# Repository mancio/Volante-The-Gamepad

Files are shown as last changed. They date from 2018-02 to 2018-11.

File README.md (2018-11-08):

# Volante-The-Gamepad
The new revolutionary joystick for car and flight simulation games.

*(Design still in progress 😆)*

&nbsp;

<p align="center">

</p>

*carbon 3d preview*

&nbsp;

<p align="center">

</p>

*3d preview with classic ABS box*

&nbsp;

<p align="center">
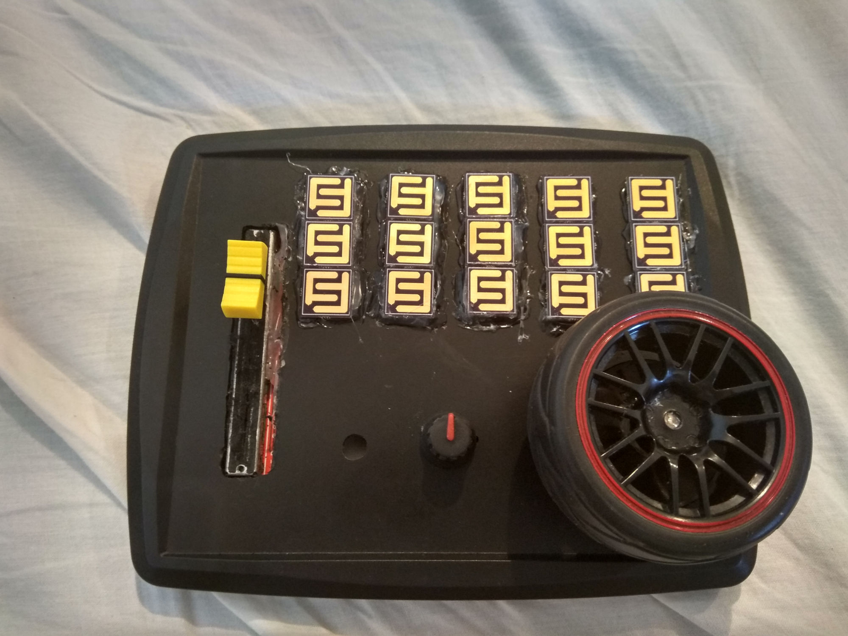
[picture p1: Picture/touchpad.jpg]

</p>   

*prototype with home-made touch buttons*

&nbsp;

<p align="center">
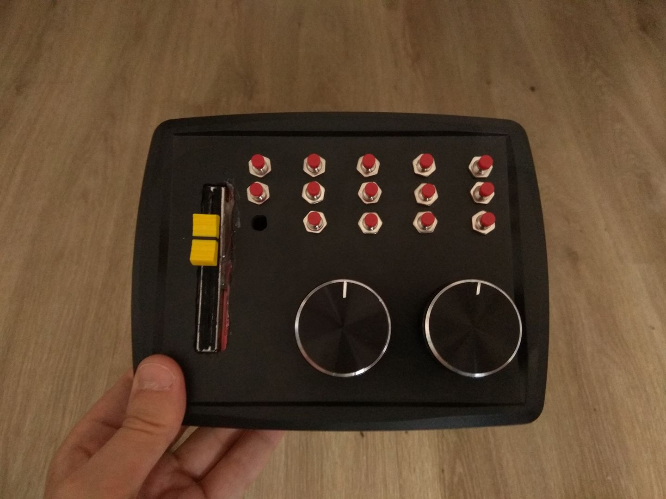
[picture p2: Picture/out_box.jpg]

</p>   

&nbsp;

*prototype with classic RC remote buttons*

### Software 
The code is written by using the famous libray ```Joystick.h```. You can find some sketches still in testing [here](https://github.com/mancio/Volante-The-Gamepad/tree/master/Volante%20sketch).
After some tests seem that only the ```JOYSTICK_TYPE_JOYSTICK``` configuration works. Unfortunately Microsoft stop to support the HID human interface and only the basic function works. Still no solution for force feedback and particular multiaxis joystick.... now the more complex gaming simulation devices have their own drivers. You don't need the basic plug and play driver. Please have a look for the [HID architecture](https://docs.microsoft.com/en-us/windows-hardware/drivers/hid/) to understand and maybe help 😵

### Hardware
The hardware include a joystick case, buttons, knobs, the [Arduino Pro Micro](https://www.sparkfun.com/products/12640) and the the shield to interface the Arduino with the gamepad hw. The button pad modules and the shield boards are designed with [KiCad](http://kicad-pcb.org/). You can find on [OSH Park](https://oshpark.com) the PCBs ready to print.
1. [First design - only push buttons](https://oshpark.com/shared_projects/Fl5pqxbd)
2. [Second design - esternal pull-up resistors](https://oshpark.com/shared_projects/2LW72doK)

### Directory structure
1. [ArduinoJoystickLibrary-master](https://github.com/mancio/Volante-The-Gamepad/tree/master/ArduinoJoystickLibrary-master) - the Joystick library written by [Matthew Heironimus](https://github.com/MHeironimus)

2. [Fritzing](https://github.com/mancio/Volante-The-Gamepad/tree/master/Fritzing) - The Fritzing project with a prototype on breadbord. A small sketch to give a basic idea.

3. [Picture](https://github.com/mancio/Volante-The-Gamepad/tree/master/Picture) - some pictures for the Fritzing design project and the building process

4. [Volante sketch](https://github.com/mancio/Volante-The-Gamepad/tree/master/Volante%20sketch) - the code
   
   - [Volante](https://github.com/mancio/Volante-The-Gamepad/blob/master/Volante%20sketch/Volante/Volante.ino) - the main Arduino sketch. The sketch is design to be used with touch, capacitive and push buttons. The I/O pin can be in PULL-UP, PULL-DOWN or FLOAT configuration. 
      - touch button design: The PINs change to LOW when the finger or any not-hi-resistance organic object connect both the pad tracks. The finger and each resistor on the shield should be considered part of a voltage devider. Your dry skin should have an internal resistance of 2 MOhm so the resistors on the shield should be >= 10 MOhm. You can use [this](http://www.ohmslawcalculator.com/voltage-divider-calculator) voltage devider calculator to calculate the resistor value. The Arduino pin mosfets are LOW state when the input is about <= 2.5V. If you use a less conductive material to close the contacts of the pad maybe you will have to raise the resistance up to 20MOhm. Remeber that an high resistance voltage devider make the input *(dancing* 🎶 *)*. You could see the button blipping when you touch the button pad (only one contact or both). This effect is usualy caused by the power supply cord (I'm testing on a laptop). To reduce this effect you should a cercamic capacitor between the input and the ground. The capacitor store a small charge when you press the button and release it very slowly due to the very high value resistors. This stop the flipping but introduce a small delay. You should try some caps between 100pF (101 value) - 100nF (104 value) until your find the best compromise for your application. I suggest 10nF (103 value) capacitor.
      
      [Here](https://www.tinkercad.com/things/0KRsWQPfhxv) Some experiments on ThinkerCad.
      
      &nbsp;
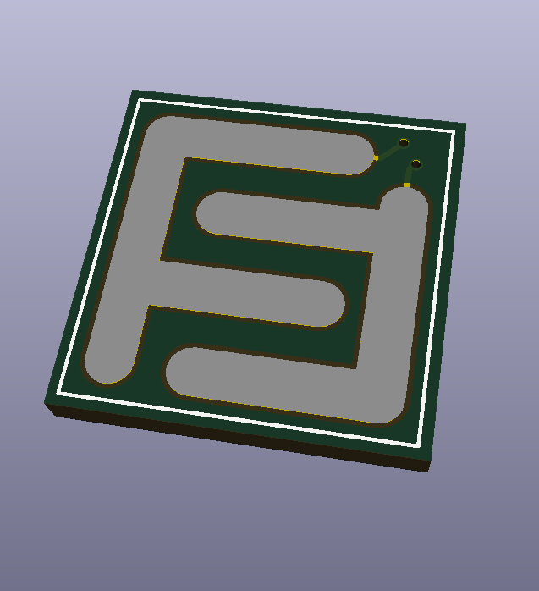
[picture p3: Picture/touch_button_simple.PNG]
      
      *touch button pad (the resistors are on the shield)* 
      &nbsp;
      
      - capacitive design: you can use the [TTP223](https://infusionsystems.com/support/TTP223.pdf) touch module as push button Normally LOW. The button switch on/off by using an internal timer that estimate the change of the capacitive charge during a fixed time slice. I suggest this configuration only for fast operation where is not required precision. The buttons are fast to trigger but sensible to external environment (high probability of fake positive) and the chip autoreset after few seconds (do not use as acceleretor button in a game)  
      
      &nbsp;
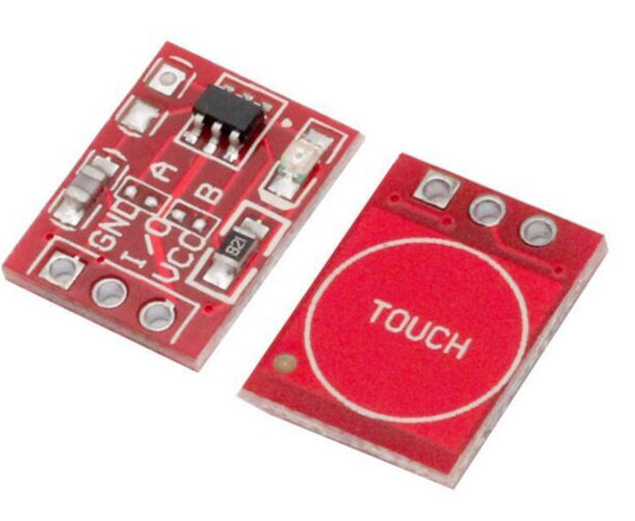
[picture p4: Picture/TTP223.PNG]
      
      *capacitive module* 
      &nbsp;
      
      - classic push button design: you can set up NO (normally open push button) using a pull-up configuration to reduce bouncing effects. When you push the button the pin will be GND. This is the most simple configuration, the button will be very reactive but harder to trigger (the most of NO push buttons are hard to click)
      
      &nbsp;
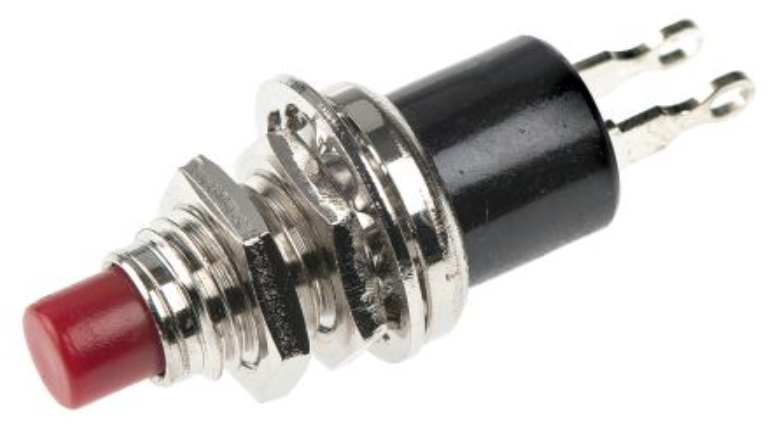
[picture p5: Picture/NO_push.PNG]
      
      *NO Momentary push button for RC* 
      &nbsp;

   - [test](https://github.com/mancio/Volante-The-Gamepad/blob/master/Volante%20sketch/test/test.ino) - Used to check the buttons assignment. 
   
      - int wiring[18] = Arduino pin in the IDE
      - int binding[18] = Buttons of joystick lib
      - String pull_mask[18] = pin state? High Low float (depending by the button type used)
      - analog_mask[18] = is analog? (for example pot is analog and push button is digital)
      
      Write the button structure with arrays here, execute the code and check in the table if the button binding is correct. If the binding satisfy your magic fingers copy this configuration to the main code ``Volante.ino``

5. [kicad](https://github.com/mancio/Volante-The-Gamepad/tree/master/kicad) - the Kicad scheme and PCB project.

   - [buttons_layout](https://github.com/mancio/Volante-The-Gamepad/tree/master/kicad/buttons_layout) - the blueprint of the gamepad case with RC push buttons
   
   - [buttons_layout_touch](https://github.com/mancio/Volante-The-Gamepad/tree/master/kicad/buttons_layout_touch) - the blueprint of the gamepad case with touch buttons
   
   - [lib](https://github.com/mancio/Volante-The-Gamepad/tree/master/kicad/lib) - kicad libraries of this project (include in kicad before open the project)
   
   - [shield](https://github.com/mancio/Volante-The-Gamepad/tree/master/kicad/shield) - firrst shield design only for capacitive and push buttons
   
      &nbsp;
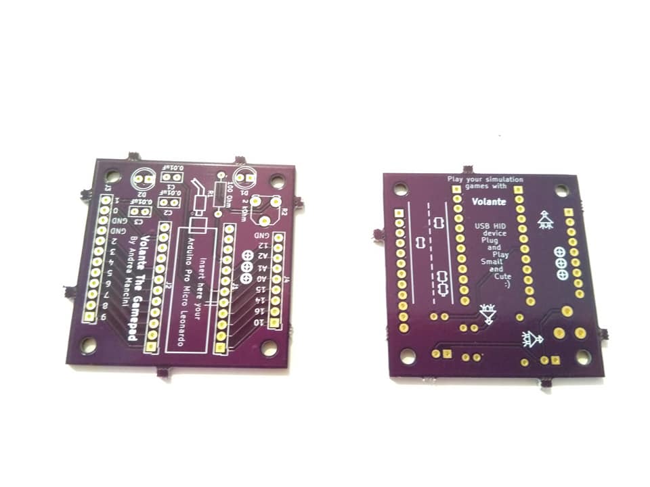
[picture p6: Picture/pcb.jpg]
      
      *First PCB printed by OSH Park* 
      &nbsp;
      
      &nbsp;
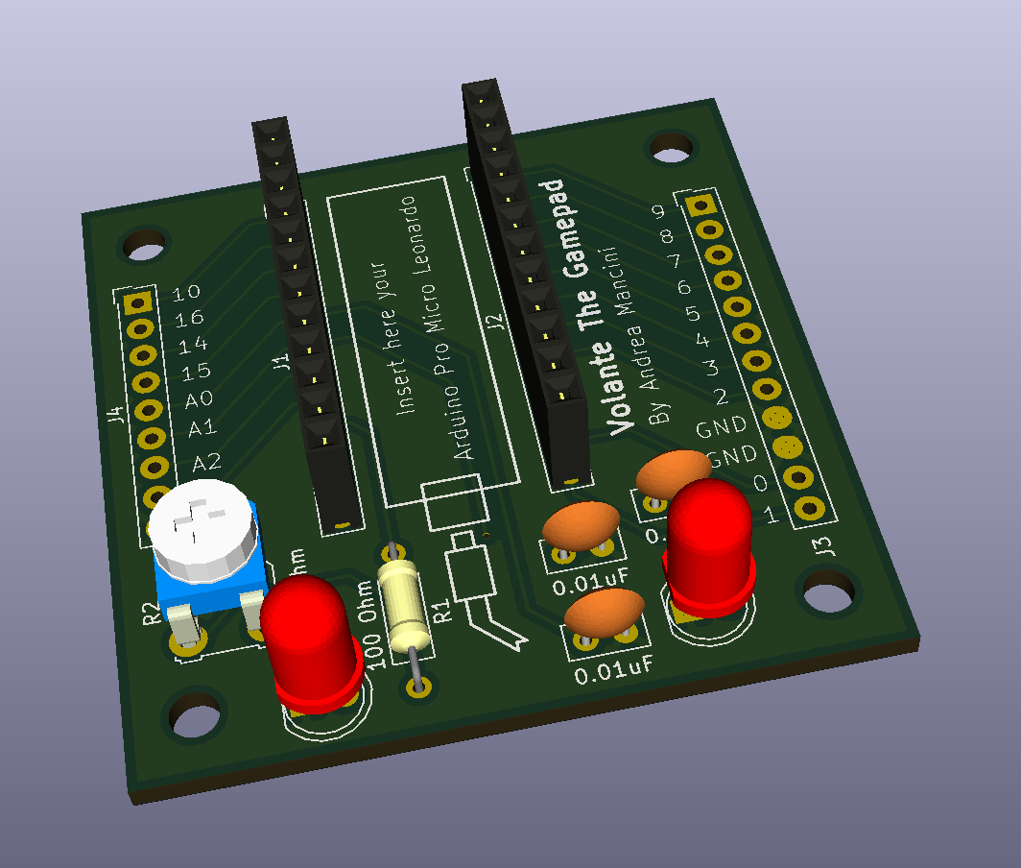
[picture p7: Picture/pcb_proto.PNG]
      
      *First PCB 3D view design by KiCad* 
      &nbsp;
   
   - [shield_touch](https://github.com/mancio/Volante-The-Gamepad/tree/master/kicad/shield_touch) - second shield design with extaernal pull-up resistor for push, capacitive and touch buttons.
   
      &nbsp;
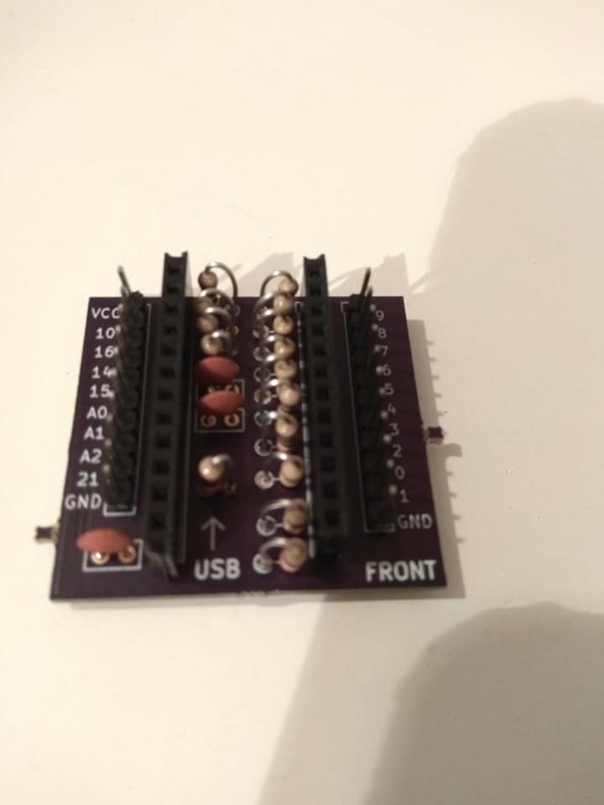
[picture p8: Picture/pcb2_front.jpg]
      
      *Second PCB printed by OSH Park and assembled manually* 
      &nbsp;
      
      &nbsp;
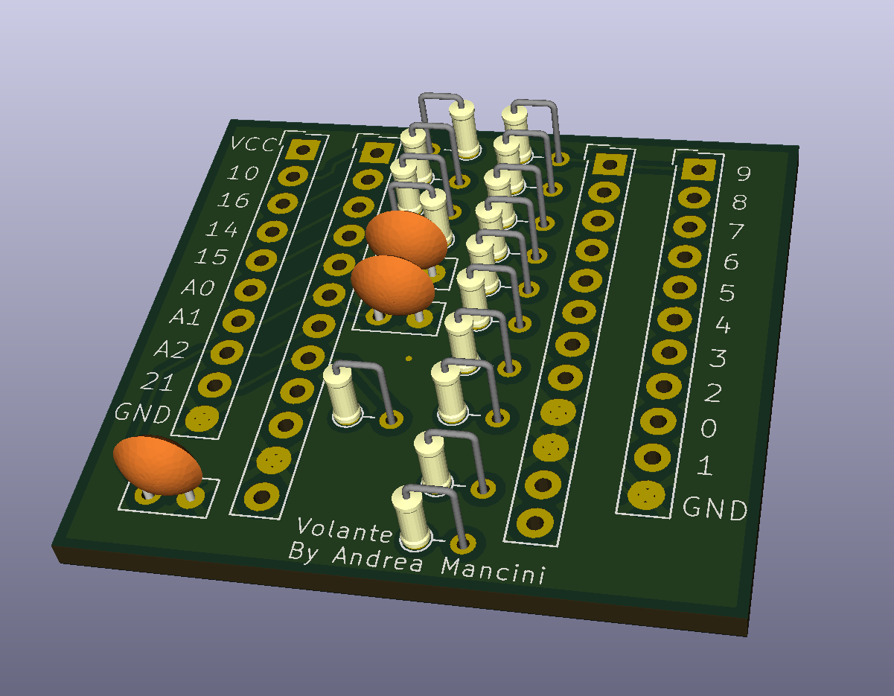
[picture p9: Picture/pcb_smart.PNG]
      
      *Second PCB 3D view design by KiCad* 
      &nbsp;
   
   - [touch_button_fancy](https://github.com/mancio/Volante-The-Gamepad/tree/master/kicad/touch_button_fancy) - alternative push button PCB design
   
   - [touch_button_simple](https://github.com/mancio/Volante-The-Gamepad/tree/master/kicad/touch_button_simple) - main push button PCB design

6. [Assetto Corsa/Lotus GT Dream](https://github.com/mancio/Volante-The-Gamepad/tree/master/Assetto%20Corsa/Lotus%20GT%20Dream) - See *Cars for Assetto Corsa*

7. [Gamepad 3d design](https://github.com/mancio/Volante-The-Gamepad/tree/master/Gamepad%203d%20design) - 3d model of the gamepad Volante

      &nbsp;
      
      *3D rendering plastic box* 
      &nbsp;
   
### Game Setup

How to set up the Volante for a Awesome gaming experience

1. [Assetto corsa](https://www.assettocorsa.net/en/)

   &nbsp;
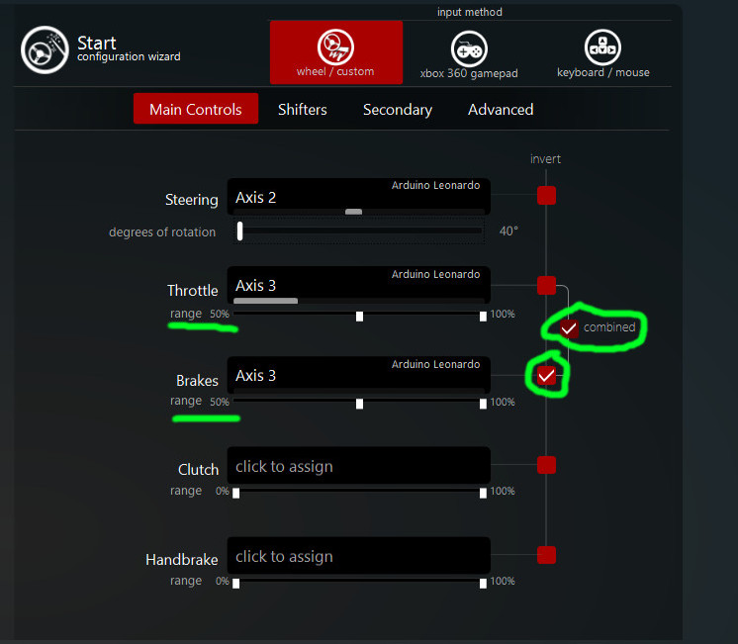
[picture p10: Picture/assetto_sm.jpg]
   
   *Main control configuration* 
   &nbsp;
   
   &nbsp;
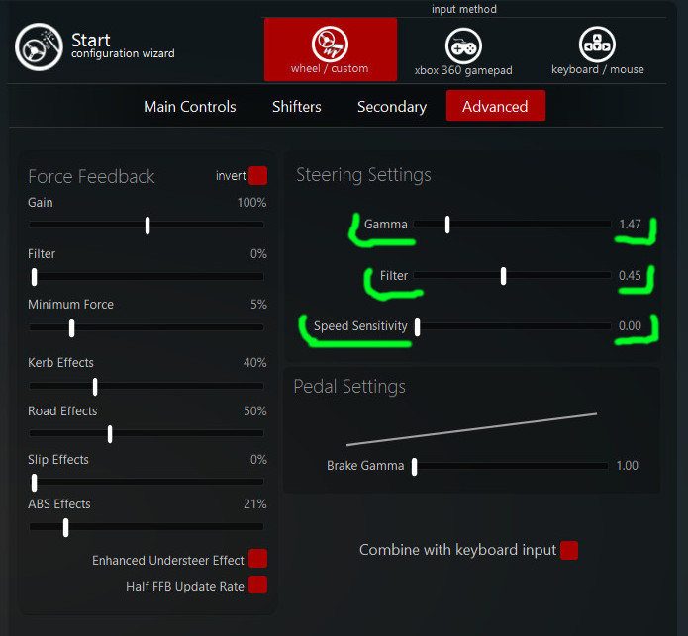
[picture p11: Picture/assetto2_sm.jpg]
   
   *Steering settings* 
   &nbsp;
   
### Cars for Assetto Corsa

To make the life easy to all the funs of the amazing game Assetto Corsa I decided to build my own cars (big tail and stick to the ground :red_car:). In the folder you find the game data and the blend file made with [blender](https://www.blender.org/)

1. [Lotus GT Dream](https://github.com/mancio/Volante-The-Gamepad/tree/master/Assetto%20Corsa/Lotus%20GT%20Dream)
   
### Facebook

You can find my project on Facebook on [Andrea Mancini's Machines](https://www.facebook.com/pg/mancio.tech/photos/?tab=album&album_id=2003051576403796)

### Conclusion
This project is focused to design a new kind of joystick that make pleasant the racing and flight simulation gaming experience.
The joystick will provide a slider linear potentiometer (throttle/brake), two knobs potentiometers (up/down - left/right) and 15 buttons
The innovation from the past consist in the _linear potentiometers_ that give the possibility to the player to perform absolutely precise movements.

#### Note
Don't worry if is not totally clear.... This project is still under development.

&nbsp;

#### Donation

Studying, designing and prototiping is expensive. If you believe in my project you can help me 😜 💲💲💲💲💲💲 😎

   - Bitcoin ```1KB6oxVrh5P6SbwFdtNHSG1rqPmdsaTaDV```

   - ETH ```0x7a5b81b2174748d6573a9ebf6b16d07c634c3e4f```

   - Litecoin ```LdVFaYbAsx9txhjVk1KURWvXqpVFDyT35k```

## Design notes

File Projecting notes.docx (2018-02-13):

Developing questions

https://forum.arduino.cc/index.php?topic=509622.0

https://arduino.stackexchange.com/questions/46213/arduino-force-feedback-vibration-gamepad

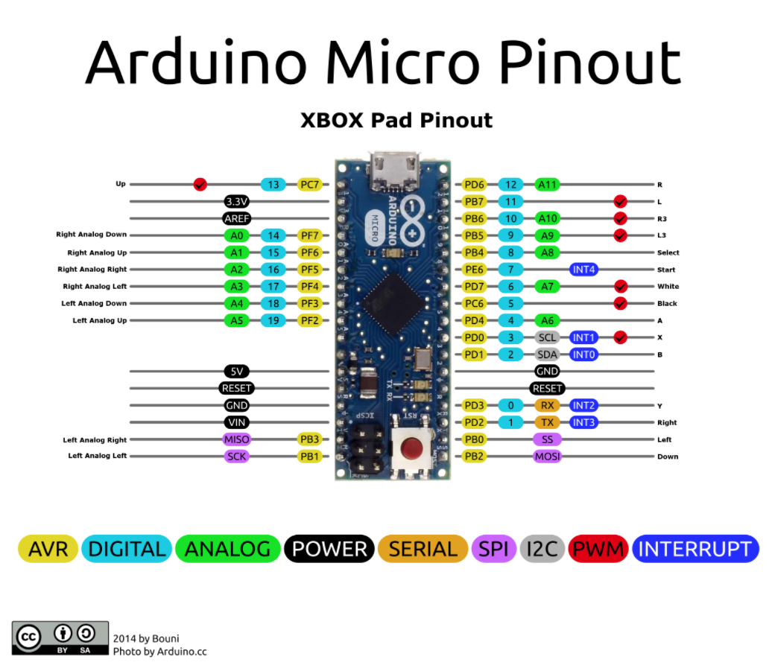
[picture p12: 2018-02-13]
Picture/pinout.PNG

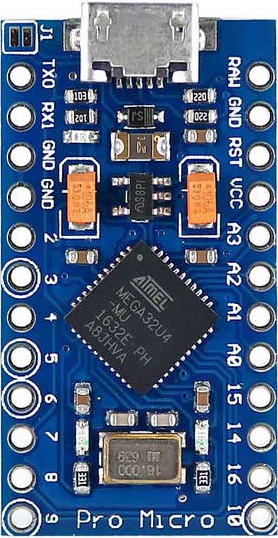
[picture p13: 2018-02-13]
Picture/pro_micro no pinout.jpg

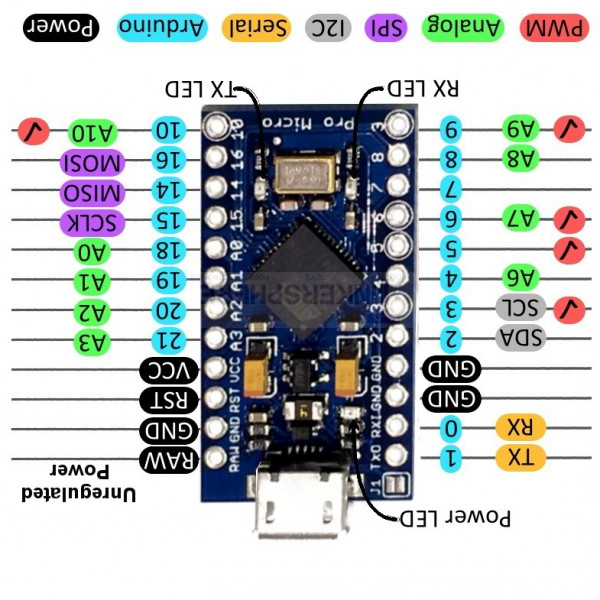
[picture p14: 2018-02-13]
Picture/pro micro pinout.jpg

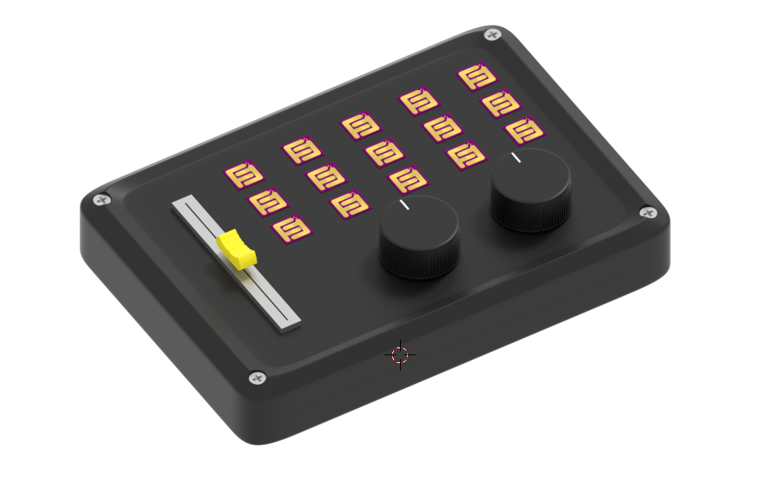
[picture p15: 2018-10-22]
Gamepad 3d design/side.PNG

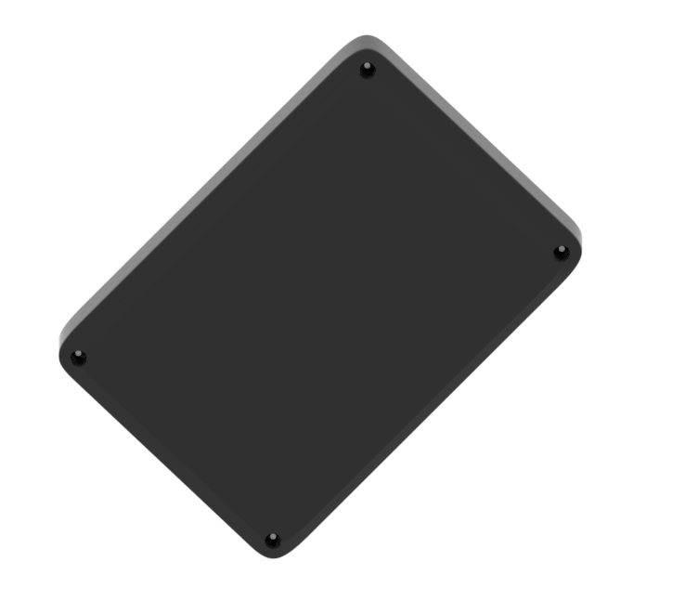
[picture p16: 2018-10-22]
Gamepad 3d design/bot.PNG

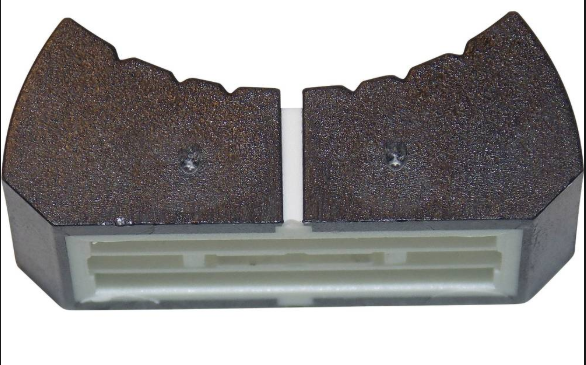
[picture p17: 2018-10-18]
Gamepad 3d design/knob.PNG

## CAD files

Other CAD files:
Assetto Corsa/Lotus GT Dream/brake.blend
Assetto Corsa/Lotus GT Dream/caliper.blend
Assetto Corsa/Lotus GT Dream/engine.blend
Assetto Corsa/Lotus GT Dream/exaust.blend
Assetto Corsa/Lotus GT Dream/front_wing.blend
Assetto Corsa/Lotus GT Dream/hub.blend
Assetto Corsa/Lotus GT Dream/lotus_GT_dream.blend
Assetto Corsa/Lotus GT Dream/rim.blend
Assetto Corsa/Lotus GT Dream/spark.blend
Assetto Corsa/Lotus GT Dream/steering.blend
Assetto Corsa/Lotus GT Dream/wing.blend
Gamepad 3d design/Volante.blend
Gamepad 3d design/button.blend
Gamepad 3d design/knob.blend

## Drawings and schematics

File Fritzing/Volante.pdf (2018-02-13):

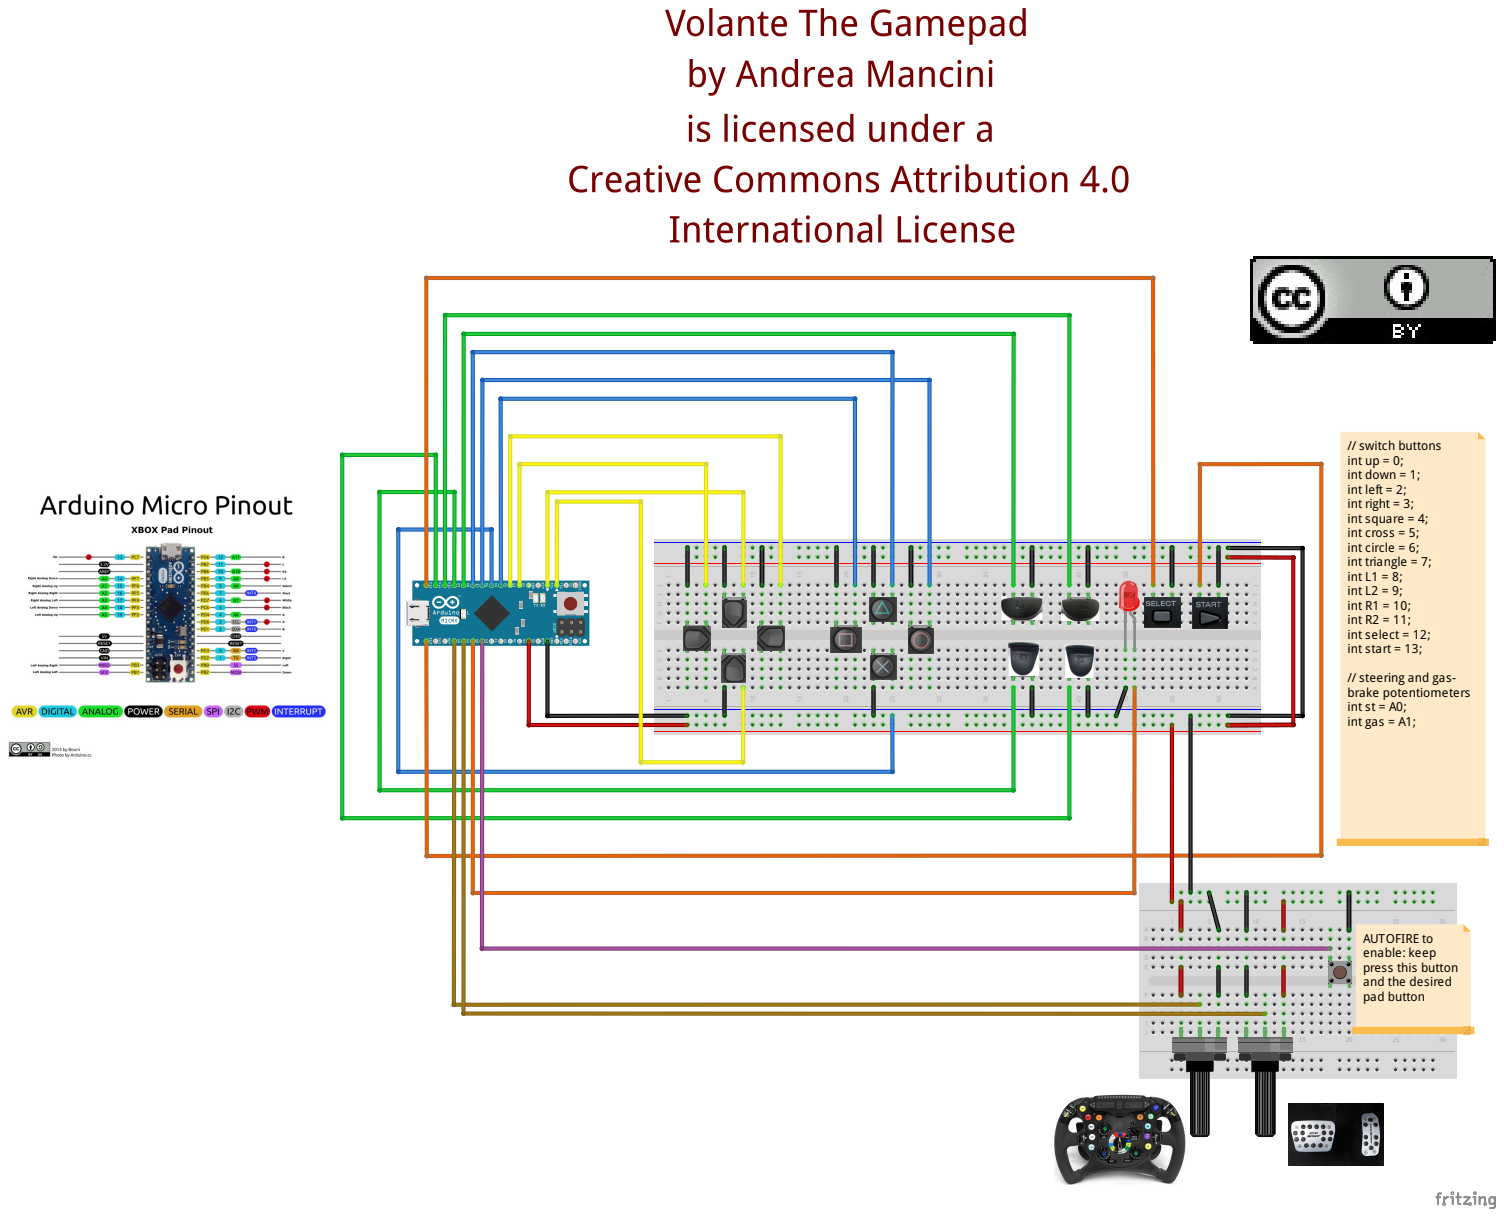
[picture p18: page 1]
// switch buttons int up = 0; int down = 1; int left = 2; int right = 3; int square = 4; int cross = 5; int circle = 6; int triangle = 7; int L1 = 8; int L2 = 9; int R1 = 10; int R2 = 11; int select = 12; int start = 13;

// steering and gas-
brake potentiometers
int st = A0;
int gas = A1;

AUTOFIRE to
enable: keep
press this button
and the desired
pad button

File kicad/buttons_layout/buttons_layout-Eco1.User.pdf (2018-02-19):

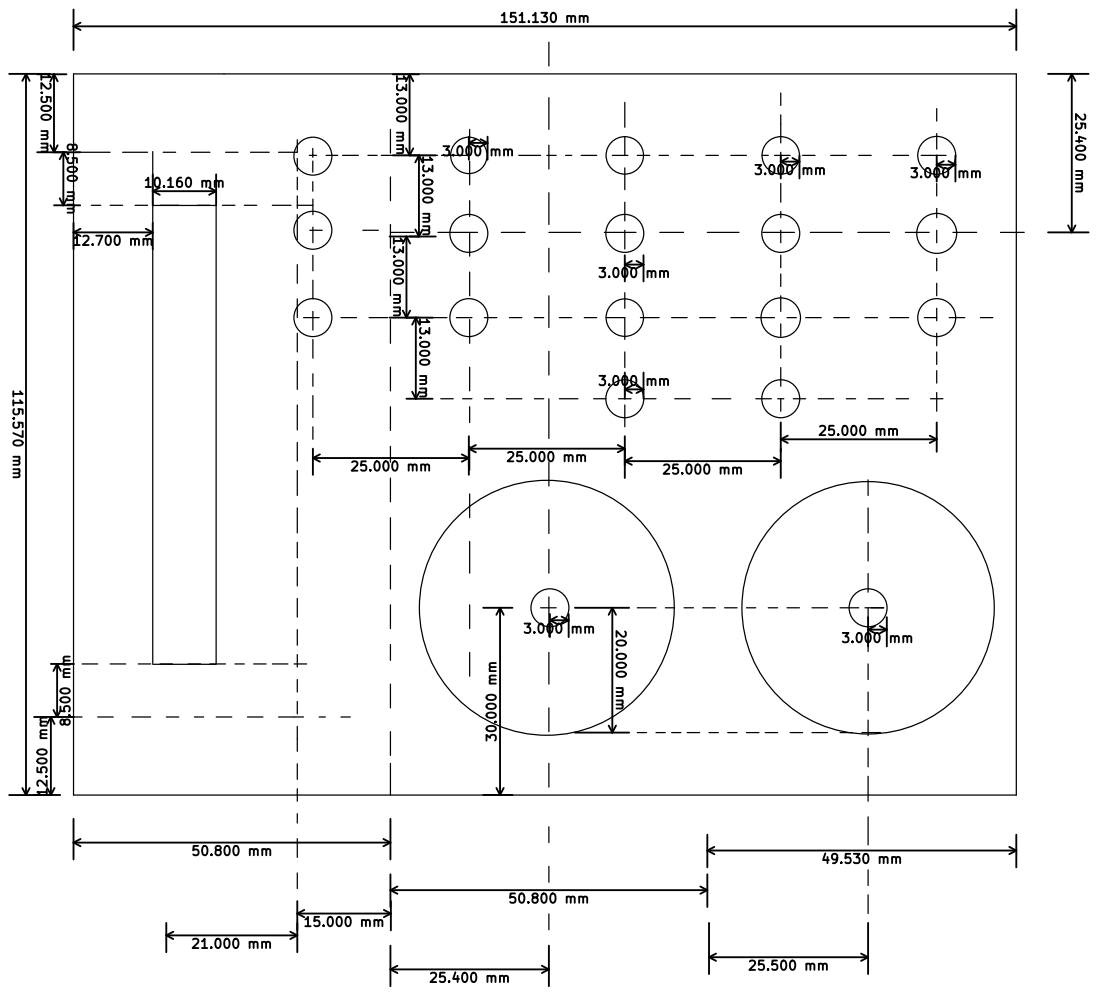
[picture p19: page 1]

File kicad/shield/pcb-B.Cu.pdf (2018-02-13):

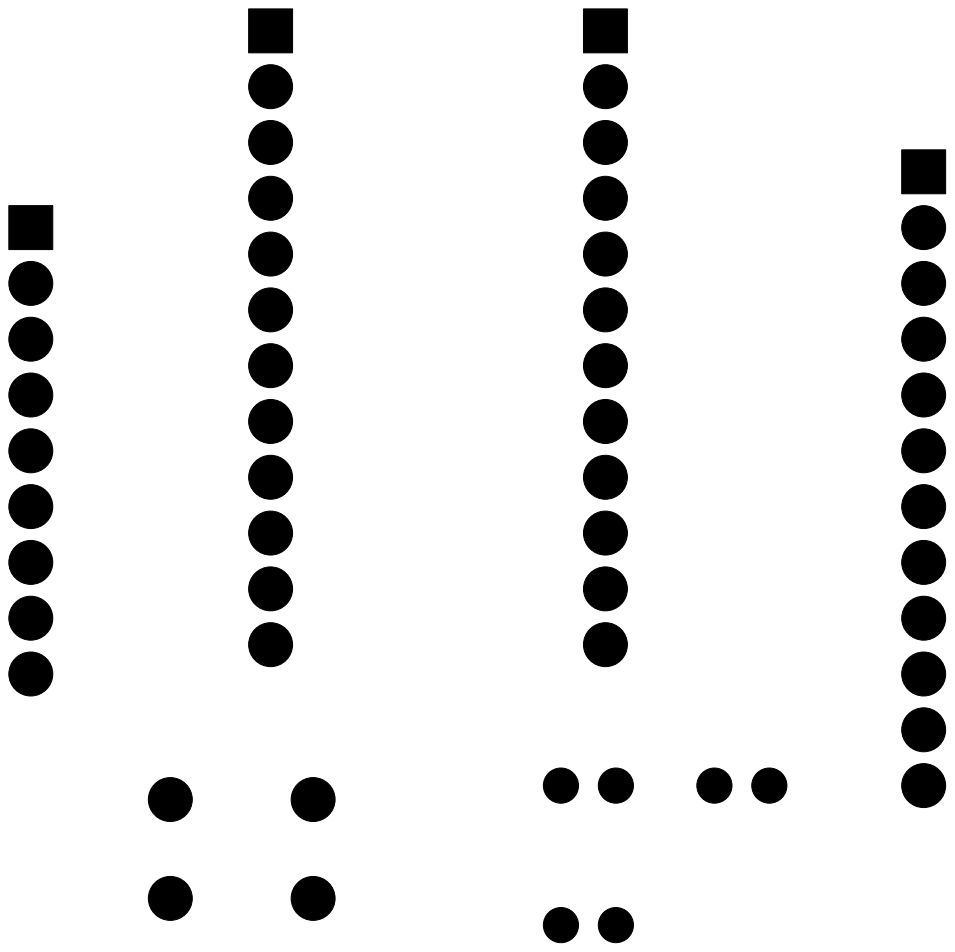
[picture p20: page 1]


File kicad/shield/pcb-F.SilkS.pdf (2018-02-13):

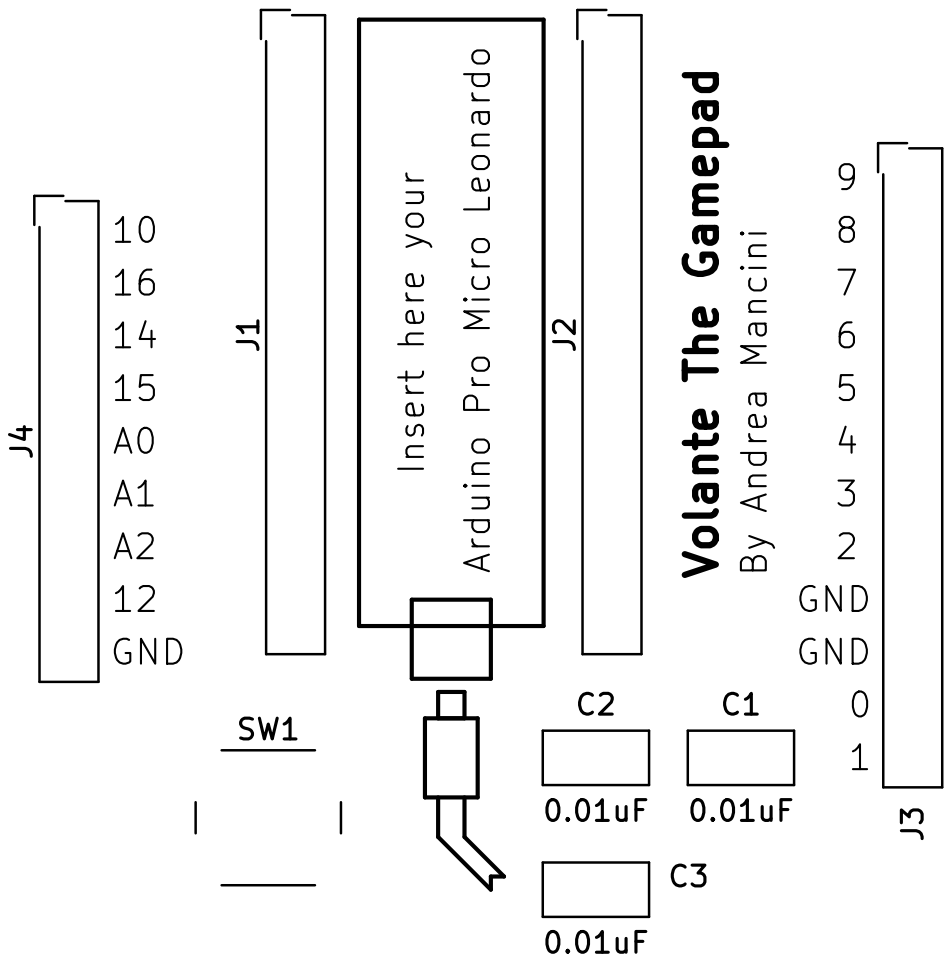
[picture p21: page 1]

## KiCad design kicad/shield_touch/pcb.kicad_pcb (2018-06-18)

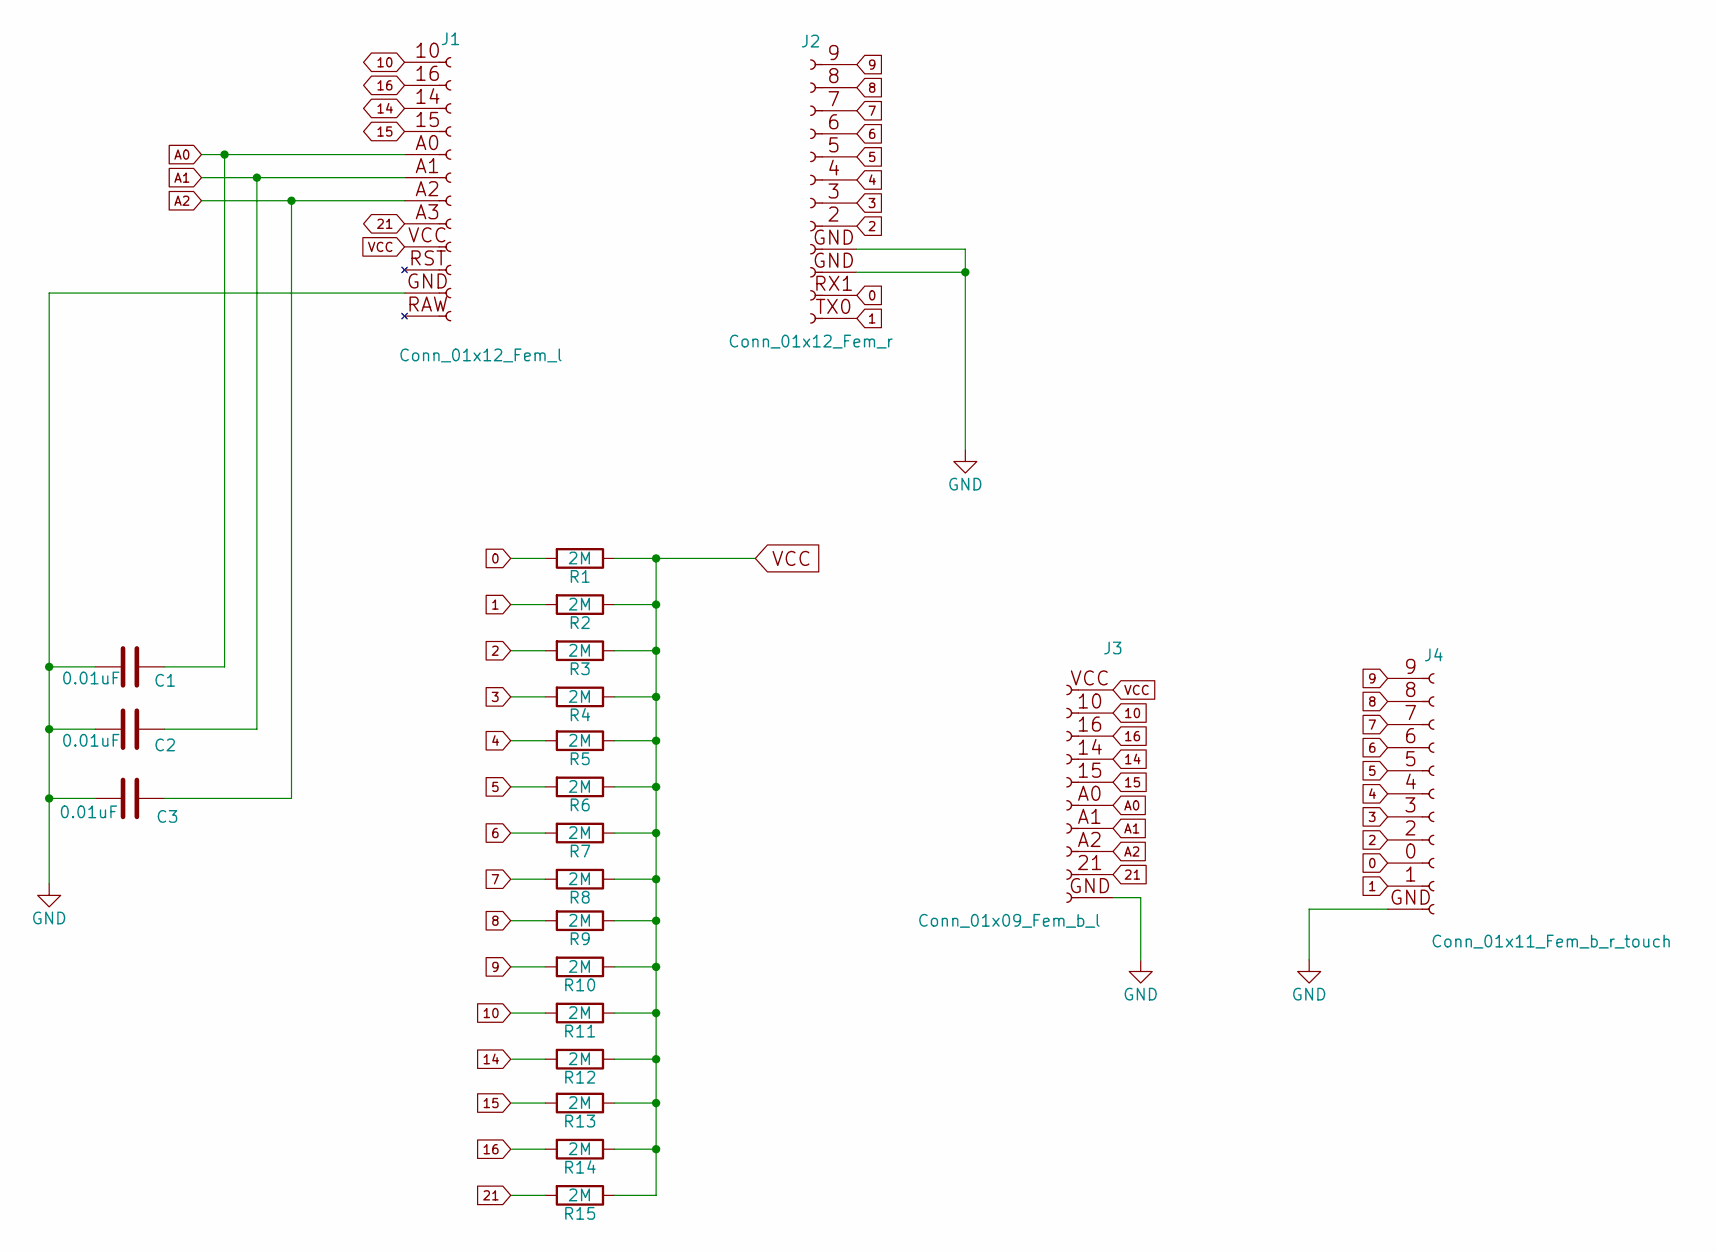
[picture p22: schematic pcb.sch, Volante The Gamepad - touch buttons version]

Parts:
C1, C2, C3: 0.01uF; C_Disc_D5.0mm_W2.5mm_P2.50mm
J1: Conn_01x12_Fem_l; SL-112-X-XX_1x12
J2: Conn_01x12_Fem_r; SL-112-X-XX_1x12
J3: Conn_01x09_Fem_b_l; SL-110-X-XX_1x10
J4: Conn_01x11_Fem_b_r_touch; SL-111-X-XX_1x11
R1, R2, R3, R4, R5, R6, R7, R8, R9, R10, R11, R12, R13, R14, R15: 2M; R_Axial_DIN0204_L3.6mm_D1.6mm_P2.54mm_Vertical

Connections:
0: J2.11, J4.9, R1.2
1: J2.12, J4.10, R2.2
2: J2.8, J4.8, R3.2
3: J2.7, J4.7, R4.2
4: J2.6, J4.6, R5.2
5: J2.5, J4.5, R6.2
6: J2.4, J4.4, R7.2
7: J2.3, J4.3, R8.2
8: J2.2, J4.2, R9.2
9: J2.1, J4.1, R10.2
10: J1.1, J3.2, R11.2
14: J1.3, J3.4, R12.2
15: J1.4, J3.5, R13.2
16: J1.2, J3.3, R14.2
21: J1.8, J3.9, R15.2
A0: C1.1, J1.5, J3.6
A1: C2.1, J1.6, J3.7
A2: C3.1, J1.7, J3.8
GND: C1.2, C2.2, C3.2, J1.11, J2.9, J2.10, J3.10, J4.11
VCC: J1.9, J3.1, R1.1, R2.1, R3.1, R4.1, R5.1, R6.1, R7.1, R8.1, R9.1, R10.1, R11.1, R12.1, R13.1, R14.1, R15.1

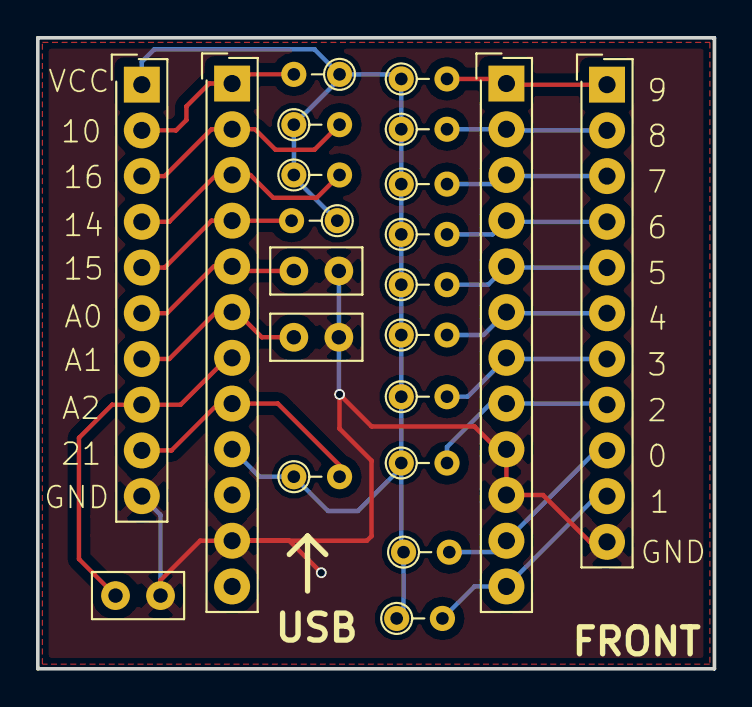
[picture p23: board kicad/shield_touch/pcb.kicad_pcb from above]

Board: 2 copper layers, 37.6 x 35.1 mm, 22 parts (0 on the bottom side), 20 nets.

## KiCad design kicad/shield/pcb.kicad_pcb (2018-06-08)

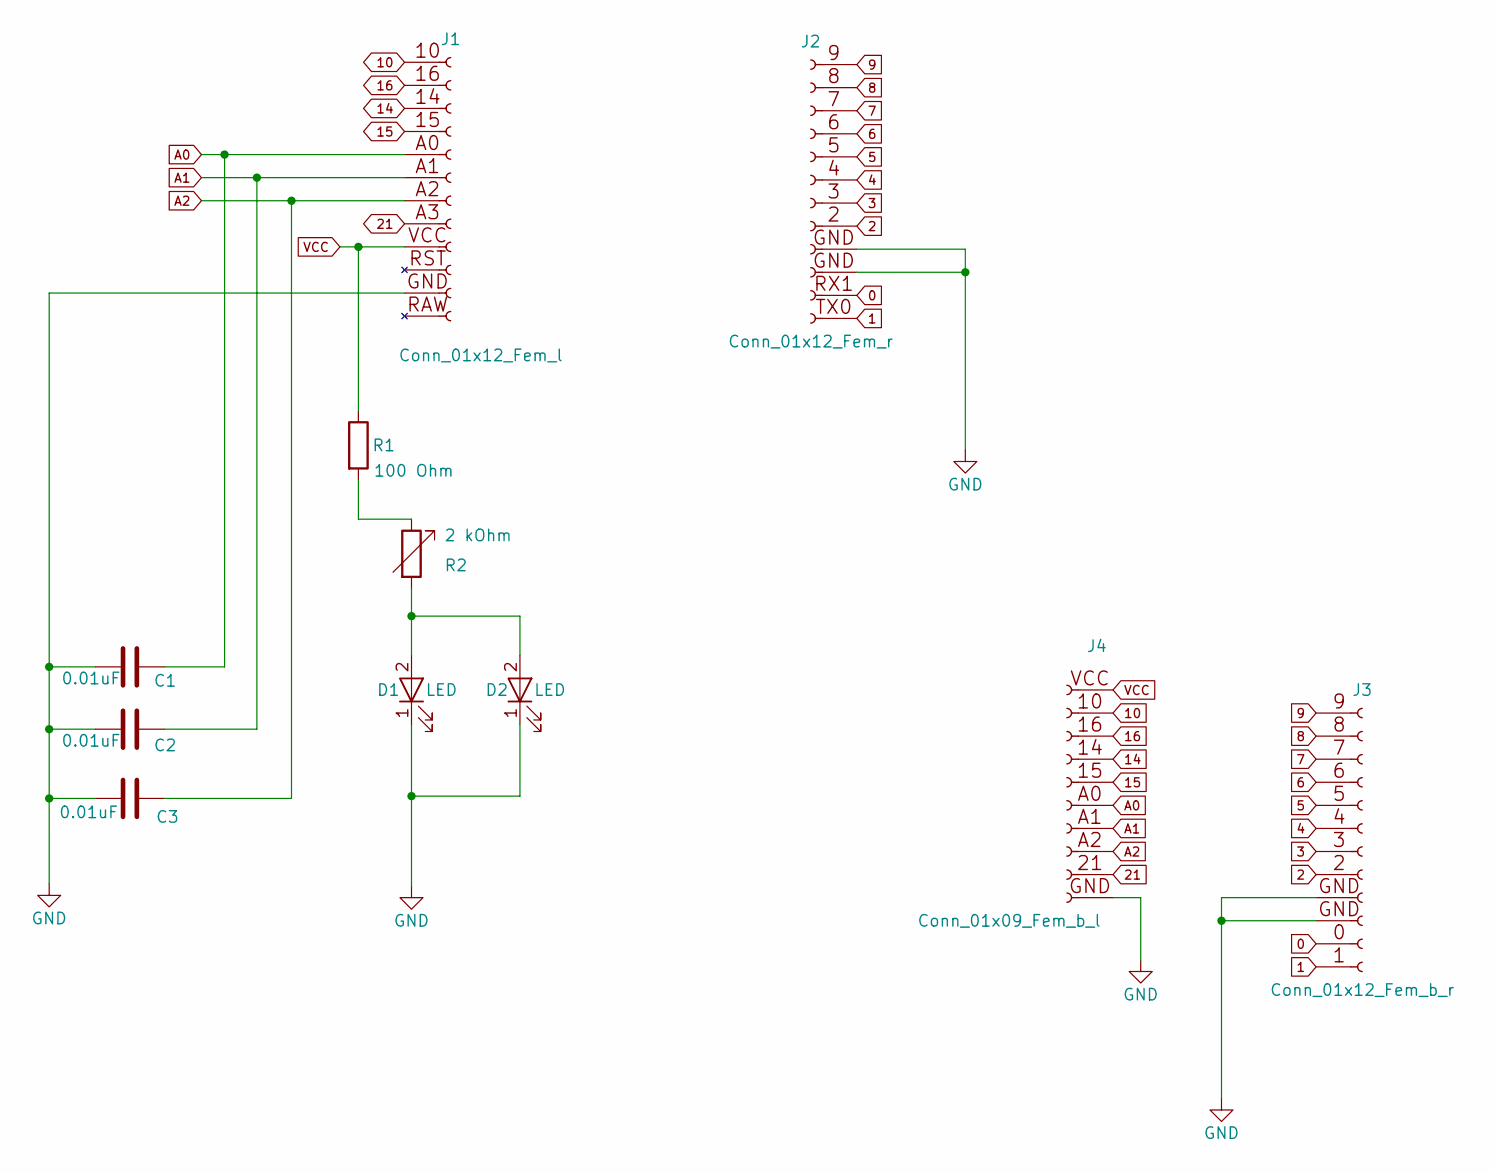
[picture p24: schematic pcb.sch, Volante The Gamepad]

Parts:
C1, C2, C3: 0.01uF; C_Disc_D5.0mm_W2.5mm_P2.50mm
D1, D2: LED; LED_D5.0mm
J1: Conn_01x12_Fem_l; SL-112-X-XX_1x12
J2: Conn_01x12_Fem_r; SL-112-X-XX_1x12
J3: Conn_01x12_Fem_b_r; SL-112-X-XX_1x12
J4: Conn_01x09_Fem_b_l; SL-110-X-XX_1x10
R1: 100 Ohm; R_Axial_DIN0207_L6.3mm_D2.5mm_P10.16mm_Horizontal
R2: 2 kOhm; Potentiometer_Triwood_RM-065

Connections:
0: J2.11, J3.11
1: J2.12, J3.12
2: J2.8, J3.8
3: J2.7, J3.7
4: J2.6, J3.6
5: J2.5, J3.5
6: J2.4, J3.4
7: J2.3, J3.3
8: J2.2, J3.2
9: J2.1, J3.1
10: J1.1, J4.2
14: J1.3, J4.4
15: J1.4, J4.5
16: J1.2, J4.3
21: J1.8, J4.9
A0: C1.1, J1.5, J4.6
A1: C2.1, J1.6, J4.7
A2: C3.1, J1.7, J4.8
GND: C1.2, C2.2, C3.2, D1.1 (K), D2.1 (K), J1.11, J2.9, J2.10, J3.9, J3.10, J4.10
unnamed: D1.2 (A), D2.2 (A), R2.2
unnamed: R1.2, R2.1
VCC: J1.9, J4.1, R1.1

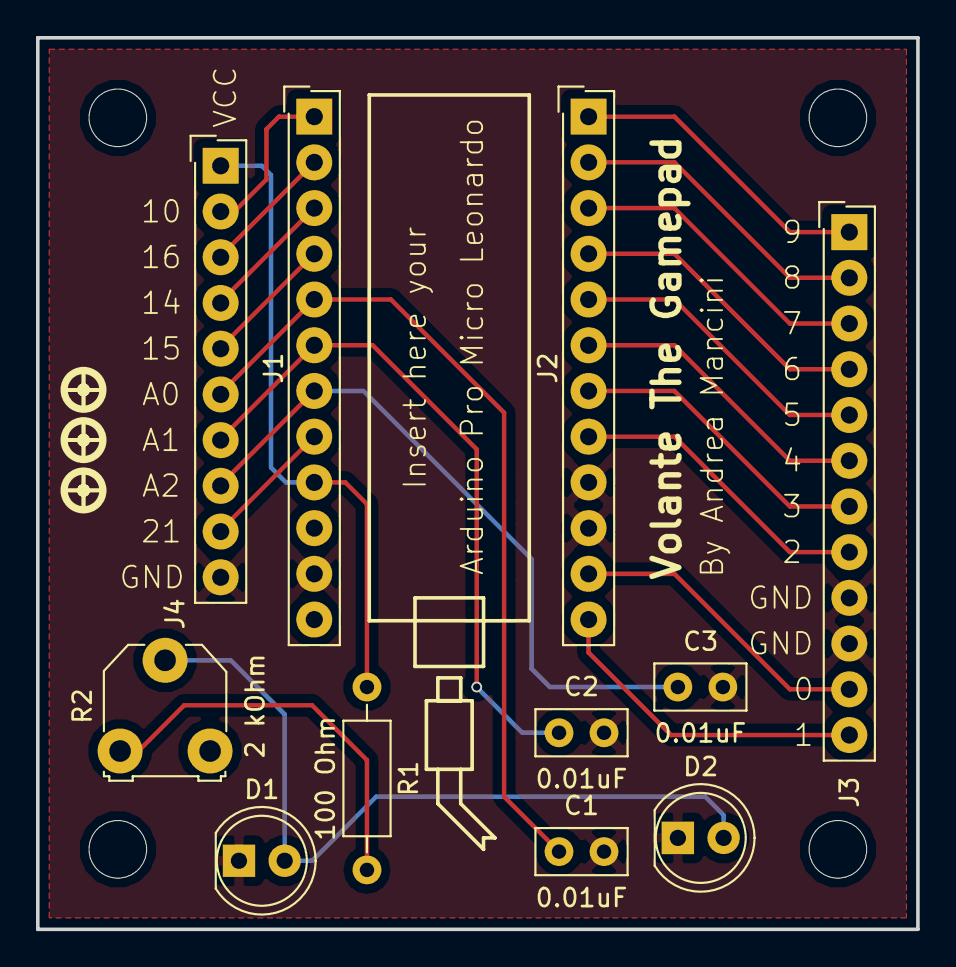
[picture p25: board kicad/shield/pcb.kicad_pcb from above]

Board: 2 copper layers, 48.9 x 49.5 mm, 11 parts (0 on the bottom side), 22 nets.

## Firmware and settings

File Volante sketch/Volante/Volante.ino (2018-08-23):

/* Volante The Gamepad
 *  
 *  Multi Version - for car and flight simulators, three axis (one slider and two knobs) and 15 buttons 
 *  
 *  Possibility to: 
 *  - free assign the IDE pin number to the Button lib numbers
 *  - use a mixing layout with simple pull-up touch, capacitive or classic push buttons
 *  
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
 *  
 *  https://github.com/MHeironimus/ArduinoJoystickLibrary
 *  https://www.arduino.cc/en/Tutorial/Debounce
 *  
 *  mail: mancioman2@gmail.com
 *  
 *  
 *  BUTTON CONFIGURATION
 *  
 *  --- BUTTONS ---
 *  ONE = 0 / RX1
 *  TWO = 1 / TX0
 *  THREE = 2
 *  FOUR = 3
 *  FIVE = 4
 *  SIX = 5
 *  SEVEN = 6
 *  EIGHT = 7
 *  NINE = 8
 *  TEN = 9
 *  ELEVEN = 10
 *  TWELVE = 14 
 *  THIRTEEN = 15 
 *  FOURTEEN = 16 
 *  FIFTEEN = 21 / A3
 *  
 *  
 *  --- AXIS ---
 *  
 *  A2 = X
 *  A0 = Y
 *  A1 = Z
 *  
 *  The HOT KEY is the button that center the Z axis when keep pressed.
 *  Is useful when the car lose control to free the wheels and keep control back. 
 *  
 *  To set the HOT KEY:
 *  - disconnect Volante from PC
 *  - keep pressed a digital button
 *  - connect the USB cable
 *  - wait more than 5 sec
 *  - release the button
 *  
 *  If potentiometers don't work properly probably 
 *  they are dirty inside. Open the metal cover and clean
 *  the part between the grafite and the brush
 *  
 *  If the axies still vibrate, try to reduce the ohm capacity of the small capacitors to 1uF
 *  
 */

#include <Joystick.h>

// axes are int in the array mask
#define X 997
#define Y 998
#define Z 999

// joystick configuration
Joystick_ Joystick(
  JOYSTICK_DEFAULT_REPORT_ID, // joystick ID 
  JOYSTICK_TYPE_JOYSTICK, // device type
  15, // buttons number (up,right,left,down are 2 axis)
  0,
  true, // X axis
  true, // Y axis
  true, // Z axis
  false, // X rotation?
  false, // Y rotation?
  false, // Z rotation?
  false, // rudder
  false, // throttle
  false, // accelerator
  false, // brake
  false // steering
);

// reverse X and Y axis - true = reversed
bool rev_X = false; 
bool rev_Y = false; 


// the Button elements
struct BUTTON {

  int number; // pin number in Arduino IDE
  int pad; // number on gamepad
  String pull; // pull-up, pull-down or float
  boolean analog; // yes or no?
  boolean is_hot; // is this button the hot_key?
};


int wiring[18] = {

   // copy and paste here your button layout (the numbers in Arduino IDE)
   
   A2, // steering
   A0, // alt
   A1, // gas analogic potentiometers pins
   
   0,
   1,
   2,
   3,
   4,
   5,
   6,
   7,
   8,
   9,
   10,
   14,
   15,
   16,
   21 // Arduino IDE pin number
     
};

int binding[18] = {

  // copy and paste here your button layout (the numbers as they are recognized in Windows)
  // remember the joystick lib start counting from zero
  
  X, // steering
  Y, // alt
  Z, // gas analogic potentiometers pins

  0,
  1,
  2,
  3,
  4,
  5,
  6,
  7,
  8,
  9,
  10,
  11,
  12,
  13,
  14 // Arduino IDE pin number
  
};

// "up" = pull-up, "down" = pull-down, "float" = float (not connected internally in case of extrenal pull resistors)
String pull_mask[18] = {

  /* copy and paste here your button layout (the state of the buttons)
   * float = pin free pysically non connected 
   * down = shorted to GND (pull-down resistor https://playground.arduino.cc/CommonTopics/PullUpDownResistor)
   * up = shorted to +5V (pull-up resistor https://playground.arduino.cc/CommonTopics/PullUpDownResistor)
   */

  "float",
  "float",
  "float", // potentiometers
  
  "float",
  "float",
  "float",
  "float",
  "float", // capacitive from button 1 to 5

  "float",
  "float",
  "float",
  "float",
  "float",
  "float",
  "float",
  "float",
  "float",
  "float" // push buttons from 6 to 15
};

boolean analog_mask[18] = {

  /* copy and paste here your button layout (is this button or pot analog?)
   *  true = analog (0-1023)
   *  false = digital (0-1)
   */

  true,
  true,
  true, // A0, A1 e A2

  false,
  false,
  false,
  false,
  false,
  false,
  false,
  false,
  false,
  false,
  false,
  false,
  false,
  false,
  false // digital buttons
};

// time limit
long timer = 5000;
// disengage hot key serching
boolean active = true;

// hot_key selected
int hot_key;

// value of Z axis
int z_pow = 0;

// true = analog read zero (by sw)
boolean fake_an = false;

BUTTON bt[18]; // generate 18 buttons

// the total number of digital buttons (starting from 0)
int el_num = 17;




// Variables will change:
//int ledState = LOW;         // the current state of the output pin
int buttonState = HIGH;             // the current reading from the input pin
int lastButtonState = HIGH;   // the previous reading from the input pin

// read the state of the switch into a local variable
int reading;

// the following variables are unsigned longs because the time, measured in
// milliseconds, will quickly become a bigger number than can be stored in an int.
unsigned long lastDebounceTime = 0;  // the last time the output pin was toggled
unsigned long debounceDelay = 50;    // the debounce time; increase if the output flickers




 



// analogRead with button debouncer included
int debouncer(int button){

  // read the state of the switch into a local variable:
  reading = digitalRead(button);

  // check to see if you just pressed the button
  // (i.e. the input went from LOW to HIGH), and you've waited long enough
  // since the last press to ignore any noise:

  // If the switch changed, due to noise or pressing:
  if (reading != lastButtonState) {
    // reset the debouncing timer
    lastDebounceTime = millis();
  }

  if ((millis() - lastDebounceTime) > debounceDelay) {
    // whatever the reading is at, it's been there for longer than the debounce
    // delay, so take it as the actual current state:

    // if the button state has changed:
    if (reading != buttonState) {
      buttonState = reading;
    }
  }
 

  // save the reading. Next time through the loop, it'll be the lastButtonState:
  lastButtonState = reading;

  return lastButtonState;
  
}

// initialize the buttons
void bt_maker(){

  for(int i=0; i<=el_num; i++){

    bt[i].number = wiring[i];
    bt[i].pad = binding[i];
    bt[i].pull = pull_mask[i];
    bt[i].analog = analog_mask[i];
    bt[i].is_hot = false;  
  }
  
}





// config the gamepad
void joy_conf(){

  // Initialize Joystick Library
  Joystick.begin();

  Joystick.setXAxisRange(-1023, 1023);
  Joystick.setYAxisRange(-1023, 1023);
  Joystick.setZAxisRange(-1023, 1023);
  
 
   
}

void button_conf(){

  
  
  // Initialize Button switch Pins

  for(int i=0; i <= el_num; i++){

    if(!bt[i].analog){
      
      if(bt[i].pull == "up"){

        pinMode(bt[i].number, INPUT_PULLUP);
        
      }else if(bt[i].pull == "down" || bt[i].pull == "float"){

        pinMode(bt[i].number, INPUT);
        
      }
    }
    
  
  }
   
  

}

// shift the potentiometer scale to reach negative value of the axis
long mapper(long m, bool rev){

  if(rev){
    return map(m, 0, 1023, 1023, -1023);
  }else if(!rev){
    return map(m, 0, 1023, -1023, 1023);
  }
    
}

// true = the current button will become the hot-key (use a free button not used during the game)
boolean hot(){

  long time_now = millis();
  if(time_now >= timer && time_now <= timer + 2000 && active){
    active = false;
    return true;
  }

  return false;
}






void setup() {

  DDRD &= ~(1<<5); // disable TXLED and RXLED (TXLED is always on if the USB is tranmitting data)

  // initialize buttons
  bt_maker();
  
  // start joystick library and set axis range
  joy_conf();

  // set buttons PULLUP
  button_conf(); 

  
  
}



void loop() {
  
  
  
  // check every digital button
  for(int i=0; i <= el_num; i++){

    // analog check
    if(bt[i].analog){

      switch(bt[i].pad){

        case X:
          if(rev_X){
            Joystick.setXAxis(mapper(analogRead(bt[i].number), true));
          }else if(!rev_X){
            Joystick.setXAxis(mapper(analogRead(bt[i].number), false));
          }
          break;

        case Y:
          if(rev_Y){
            Joystick.setYAxis(mapper(analogRead(bt[i].number), true));
          }else if(!rev_Y){
            Joystick.setYAxis(mapper(analogRead(bt[i].number), false));
          }
          break;
          
        case Z:
          if(!fake_an){
            Joystick.setZAxis(mapper(analogRead(bt[i].number), false));
          }else{
            Joystick.setZAxis(z_pow);
          }
          break;
          
      }
            

    /* digital up or float (float is externally pull-up so is the same case as up)
     * remember to keep float the pin in the hw if the pin has an external pull-up resistor. The internal pull-up is between 20kΩ and 50kΩ
     */
    }else if( (!bt[i].analog && bt[i].pull == "up") || (!bt[i].analog && bt[i].pull == "float")){


      if(debouncer(bt[i].number) == LOW){

        Joystick.setButton(bt[i].pad, HIGH); // High because the open switch is +5V and close is GND
        if(hot()){
          bt[i].is_hot = true; // this button become the hot_key button
        }

        if(bt[i].is_hot){
          fake_an = true; // I'm pressing the hot key
        }
        
      }else{

        Joystick.setButton(bt[i].pad, LOW);

        if(bt[i].is_hot){
          fake_an = false; // I'm NOT pressing the hot key
        }
        
      }


    // digital down        
    }else if(!bt[i].analog && bt[i].pull == "down"){

      if(debouncer(bt[i].number) == LOW){

        Joystick.setButton(bt[i].pad, LOW);

        if(bt[i].is_hot){
          fake_an = false;
        }
      
      }else{

        Joystick.setButton(bt[i].pad, HIGH);
        if(hot()){
          bt[i].is_hot = true;
        }

        if(bt[i].is_hot){
          fake_an = true;
        }

               
      }
      
    }

      

    
  }



} 

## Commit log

2018-02-13 Add files via upload
    First commit still testing
    [Volante.fzz, buttons_layout.kicad_pcb, buttons_layout.sch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]
2018-02-13 pcb finshed
    13/02/2018
    [pcb.kicad_pcb]
2018-02-15 update
    - verify arduino socket dimension
    - change port 12 to 21
    - disable TXLED and RXLED
    [pcb.sch]
2018-02-16 maybe final
    - ultimate PCB design
    - add potentiometer for led control
    - checked connections
    [pcb.kicad_pcb, pcb.sch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]
2018-02-17 update
    - check pcb errors
    - example of BOM (not for this board)
    - BOM still TODO
    [pcb.kicad_pcb]
2018-02-17 updates
    - print the front and back copper layer to check the connections
    - add silks pictures
    - ready to print first prototype
    [pcb.kicad_pcb]
2018-02-19 update
    - layout in pdf
    - moved slider on the left
    - moved pin test
    [buttons_layout.kicad_pcb]
2018-02-22 update
    - fix the code SPI pins can be used as digital input but they need an external 10K pull-up resistor
2018-02-28 update
    - fix the code
    - SPI ports working (the problem was the GND wire unsoldered)
    - all buttons are working
2018-04-16 capacitive buttons
    - to fix
2018-05-16 update
    - still to fix a lot of stuff
    [pcb.kicad_pcb, pcb.sch]
2018-05-19 update
    - still to fix
    [_saved_pcb.sch, pcb.kicad_pcb]
2018-05-19 update
    - still working
    [pcb.kicad_pcb]
2018-05-20 update
    - almost finished
    [pcb.kicad_pcb]
2018-05-21 update
    - drawing buttons
    - still to finish
    [touch.kicad_pcb, touch.sch]
2018-05-22 update
    - try to make a better button
    [touch.kicad_pcb, touch.sch]
2018-05-23 update
    - try to make several button layouts
    [touch.kicad_pcb, touch.sch]
2018-06-03 update
    - designing pcb with vertical resistors
    [pcb.kicad_pcb, pcb.sch]
2018-06-03 update
    - pcb complete and tested
    [pcb.kicad_pcb]
2018-06-05 update
    - resistors on front side pcb
    [pcb.kicad_pcb]
2018-06-06 update
    - pcb design pictures
2018-06-06 update
    - try to make a hole touch button... mah :-1:
2018-06-08 update
    - fix pcb
    [touch.kicad_pcb]
2018-06-08 touch button mask layout
    [buttons_layout.kicad_pcb, buttons_layout.sch]
2018-06-08 VCC pin
    - add Vcc pin
    [pcb.kicad_pcb, pcb.sch]
2018-06-18 added throught via
    - added throught via to increase GND contacts
    [pcb.kicad_pcb]
2018-06-18 added logos
    - open hw logo
    - front back logos
    [pcb.kicad_pcb]
2018-06-18 change sch and pcb page settings
    - details
    - data
    - title
    [pcb.kicad_pcb, pcb.sch]
2018-12-16 update
    better touch button pad
    [touch.kicad_pcb]

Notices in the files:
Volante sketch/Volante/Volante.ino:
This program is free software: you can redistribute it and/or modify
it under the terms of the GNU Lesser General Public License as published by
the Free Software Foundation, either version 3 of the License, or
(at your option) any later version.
